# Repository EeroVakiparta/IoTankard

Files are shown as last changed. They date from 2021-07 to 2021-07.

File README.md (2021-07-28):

# IoTankard

Curious IoT test project.
Boardgames meet one handed beer drinking controller.

# Pin allocation

| Device | Pins | Notes |
| --- |:---: | ---:|
| MX Buttons | D4,D5,D6,D7 |  Add 10k resistors |
| HC-05 BT | D2,D3 | RX, TX |
| OLED I2D | A4,A5 | SCL, SDA |
| ADXL345 | D10,D11,D12,D13 | SPI |
| MotorDriver | D9 (PWM) | Only one needed |
| IF | A2 | |

3 free digital and 5 analog pins

# TODO

- Should the motor drive 2 directions
- Should I add capasitor for motor
- Come up with the connection to laptop
- Try accelerometer SPI communication with 3 wires instead of 4
- Fix double tap provoking a single tap after
- Measure batterylife for one 18650 cell.
- Better visuals for screen

# Buttons

MX cherry copies. The key caps are yet to be decided on.
Use normal keycaps for first version.

# Motor

6V basic motor was used. Went for low durability solution and soldered a big chunk at the tip of axis. With big motor it seems a bit challenging to do short fast wibrations.

# Infrared

Things learned
- The sensor stops working if the adjustment screw is over 80 or under 20% of its rotation. Maybe cheap part.

# Casing

The Ebin game remote which this was originally supposed to be went through few brainstorming phases and finally came to a handle design. The handle can be used for future projects. For example for a single hand MMO and beer drinking controller.

1. "The Wand"

2. "The Remote"

3. "The Tankard

Trying to see if everything fits inside | Modeled all parts | Closest to final product before first print
--- | --- | ---
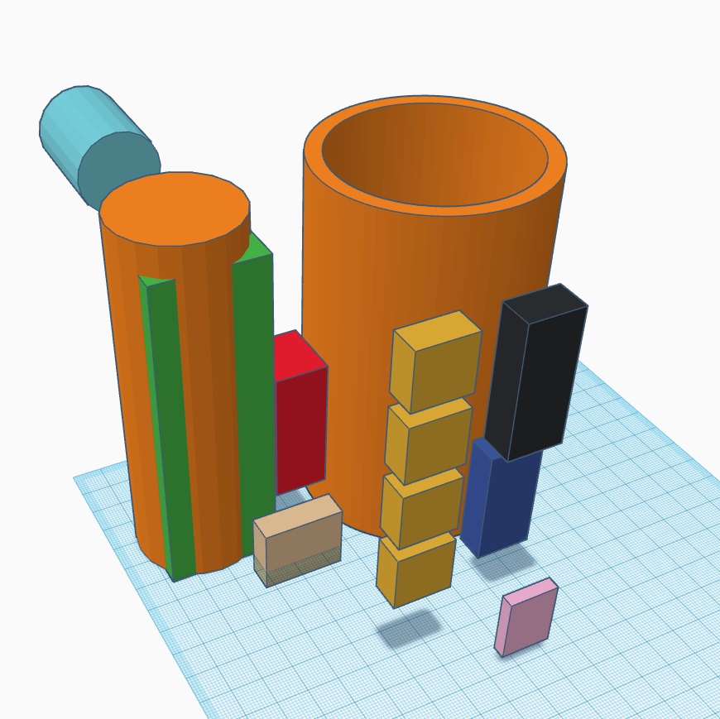
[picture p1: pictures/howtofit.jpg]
measuring how to fit everything
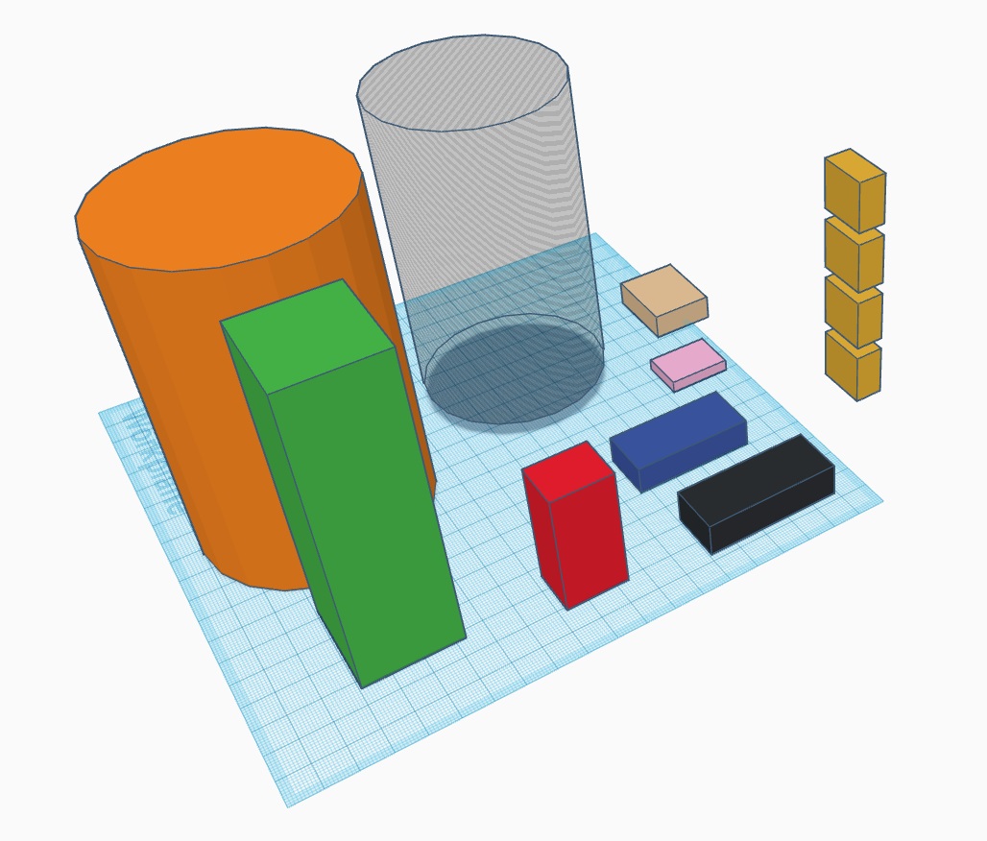
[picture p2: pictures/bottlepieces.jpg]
models of part needing to fit inside
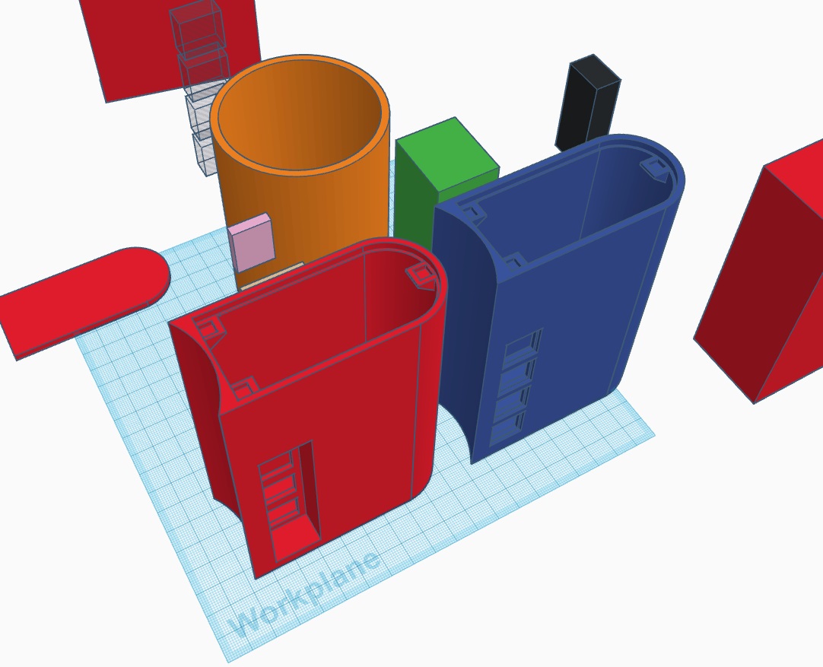
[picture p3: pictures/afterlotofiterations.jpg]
first good version
||

NOTE: next version will be done with fusion 360. At the moment of first desing I did not own any licenses to proper 3d design software.

# Bluetooth

Things learned
 - Do not spend hours of time debugging RX TX wires which are wrong way around.

The game engine this is made for can handle game controller inputs but for first version we went for bluetooth 
keyboard style and approach.

Converting the serial to key presses I used simple powershell script ( readCOM.ps1 )

```
    if ($port.IsOpen)
    {
        $data = $port.ReadLine()
        Add-Type -AssemblyName System.Windows.Forms
        [System.Windows.Forms.SendKeys]::SendWait($data);
```

| KEY | TRIGGER | NOTES | Ebin boardgame action | |
|-----|---|---|---|---|
| Q | Button | Index finger | Travel button | |
| W | Button | Middle finger | Dice | |
| E | Button | Ring finger | Group Dice | |
| R | Button | Pinkey finger | Biome Event | |
| ? | IR Sensor | Beer can removed | | |
| ? | IR Sensor | Beer can inserted | | |
| ? | Sensor | Swig taken (lenght adjustable) | | |
| ? | Sensor | Tankard falling from table | | |
| ? | Sensor | Tankard has not been in hand for 5 seconds (inactivity) | | |
| ? | Sensor | Tankard in hand | | |
| ? | Sensor | Tankard tapped on table | | |
| ? | Sensor | Tankard tapped to table twice | | |
| | Sensor | Beer can upside down (Bottoms up) | | |

Trying to explain what I'm doing to team | Some of the prototyping hardware
--- | --- 
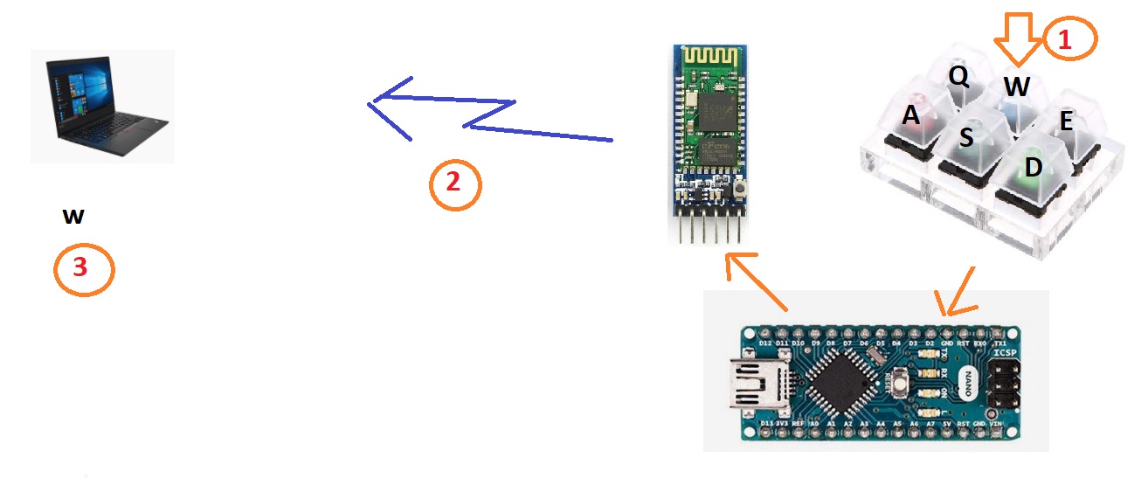
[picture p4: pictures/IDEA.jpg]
basic idea
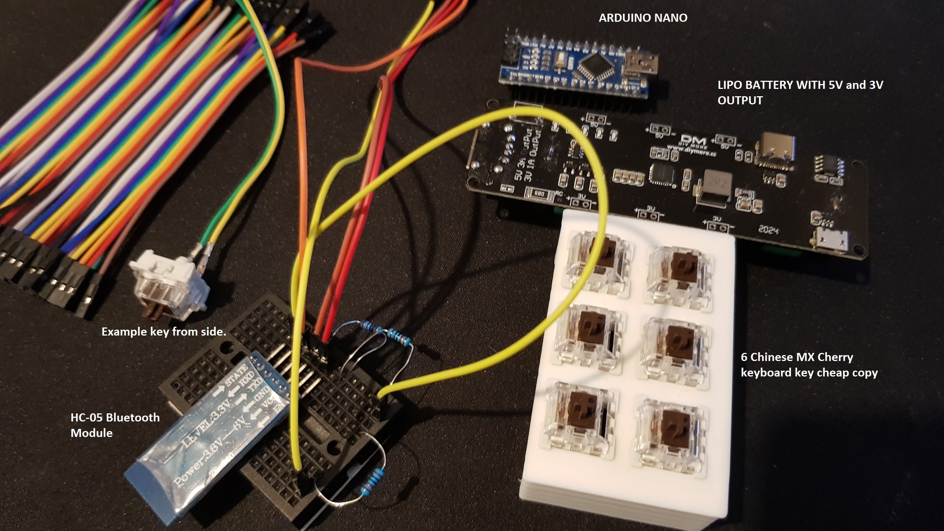
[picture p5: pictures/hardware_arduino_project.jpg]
 |

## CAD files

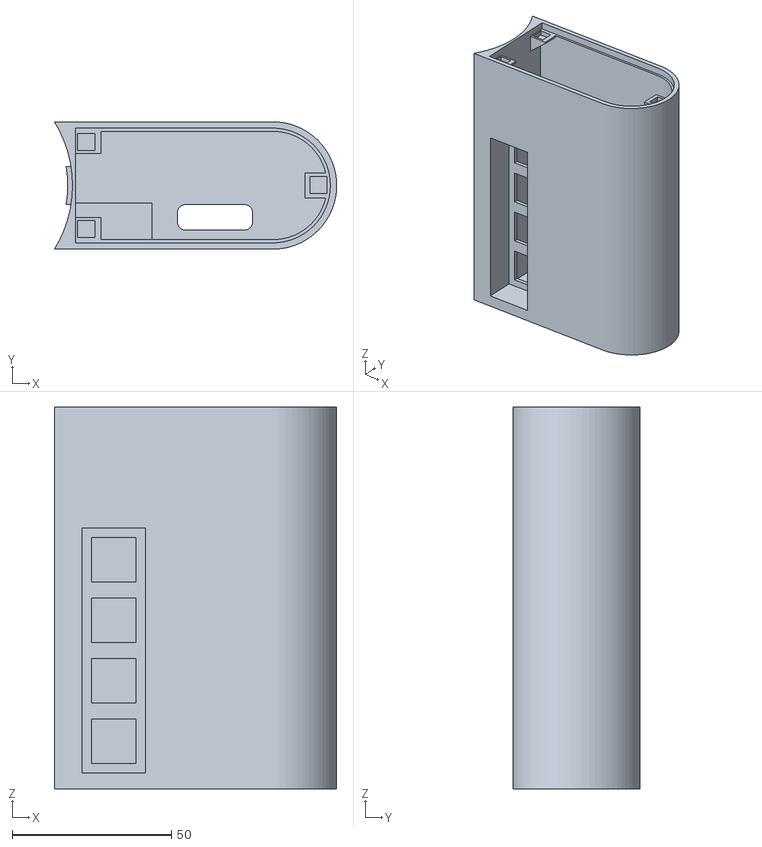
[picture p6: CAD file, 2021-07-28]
STL/handleversion_4.stl
88.7 x 40.0 x 120.0

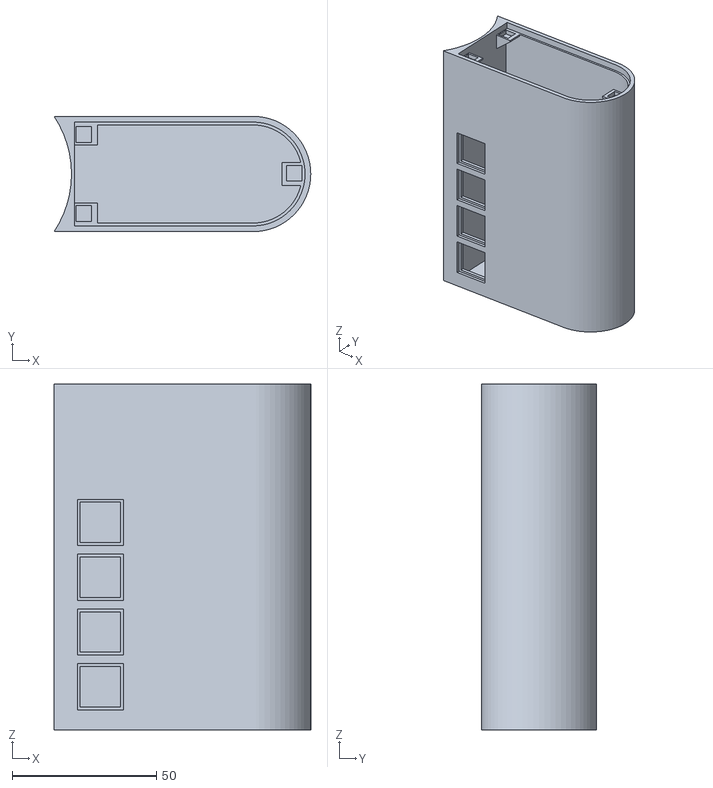
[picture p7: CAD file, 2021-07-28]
STL/handleversion_2.stl
89.0 x 40.0 x 120.0

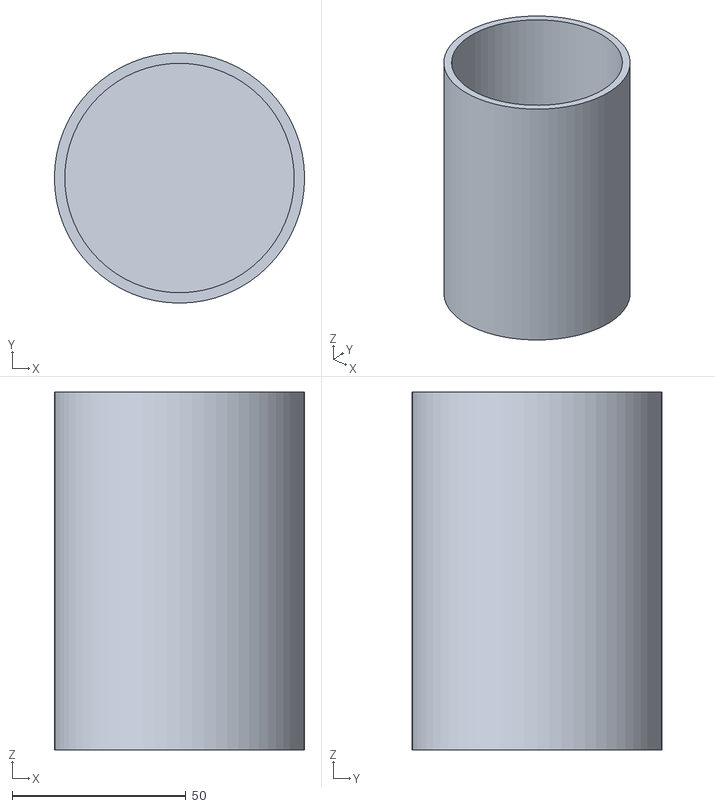
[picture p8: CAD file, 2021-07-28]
STL/canpart_1.stl
72.0 x 72.0 x 103.0

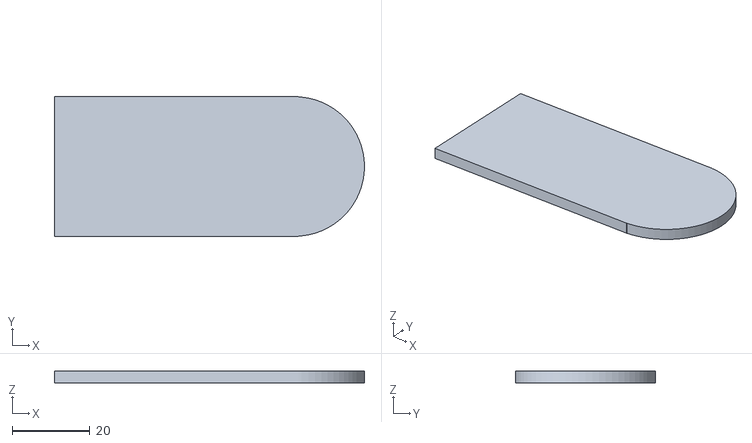
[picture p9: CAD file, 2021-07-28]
STL/lid.stl
80.0 x 36.0 x 3.00

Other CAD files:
STL/handleversion_1.stl
STL/handleversion_3.stl

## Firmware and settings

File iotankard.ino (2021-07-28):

#include <SparkFun_ADXL345.h> // accelerometer
#include <SoftwareSerial.h>  // Bluetooth

// Screen //
#include <SPI.h>
#include <Wire.h>
#include <Adafruit_GFX.h>
#include <Adafruit_SSD1306.h>

#define SCREEN_WIDTH 128 
#define SCREEN_HEIGHT 32 

#define OLED_RESET     -1 // Reset pin # (or -1 if sharing Arduino reset pin)
#define SCREEN_ADDRESS 0x3C ///< See datasheet for Address; 0x3D for 128x64, 0x3C for 128x32
Adafruit_SSD1306 display(SCREEN_WIDTH, SCREEN_HEIGHT, &Wire, OLED_RESET);

// Bluetooth //
SoftwareSerial bt(2,3); // RX/TS pins as parameters remember to cross wire these

// Accelerometer //
ADXL345 adxl = ADXL345(10);           // SPI com ADXL345(CS_PIN);

// Motor //
int IN1 = 9;
int motorSpeed = 10;
int maxVibrateSpeed = 255;
int minVibrateSpeed = 40;

// Buttons //
int buttonDelay = 100;
int buttonPressed = 0;

const int indexFinger_ButtonPin = 5;
const int middleFinger_ButtonPin = 6;
const int ringFinger_ButtonPin = 7;
const int pinkey_ButtonPin = 8;

int indexFinger_Btn;
int middleFinger_Btn;
int ringFinger_Btn;
int pinkey_Btn;

// IR sensor //
int IRsensor = A2;

// Status variables //
bool drinkLoaded = false;
bool sipTaken = false;
int sipcount = 0;

void setup() {
  Serial.begin(9600);
  bt.begin(9600);


  /* Screen */
  // SSD1306_SWITCHCAPVCC = generate display voltage from 3.3V internally
  if(!display.begin(SSD1306_SWITCHCAPVCC, SCREEN_ADDRESS)) {
    Serial.println(F("SSD1306 allocation failed"));
    for(;;); // Don't proceed, loop forever
  }

  // Clear the buffer
  display.clearDisplay();
  display.setCursor(0, 0);
  delay(200);
  
  
  adxl.powerOn();
  adxl.setRangeSetting(16);           // range in G (2,4,8,16) Drawback with higher Gs is lower sensitivity
  adxl.setSpiBit(0);                  // 0 = 4wire SPI , 1=3wire SPI

  adxl.setActivityXYZ(1, 0, 0);       // Which axis the activity feature uses
  adxl.setActivityThreshold(75);      // Adjust sensitivity of previous 62.5mg per increment (0-255)

  adxl.setInactivityXYZ(1, 0, 0);     // Which axis the inactivity feature uses
  adxl.setInactivityThreshold(75);    // 62.5mg per increment (0-255)
  adxl.setTimeInactivity(10);         // Sec to inactivity to activate

  adxl.setTapDetectionOnXYZ(0, 0, 1); // Selection of tap features axis

  adxl.setTapThreshold(50);           // 62.5 mg /step Tap strenght (0-255)
  adxl.setTapDuration(15);            // 625 μs /step
  adxl.setDoubleTapLatency(80);       // 1.25 ms /step Doubletap
  adxl.setDoubleTapWindow(200);       // 1.25 ms /step

  adxl.setFreeFallThreshold(7);       // Free fall (5 - 9) recommended - 62.5mg per increment (0-255)
  adxl.setFreeFallDuration(30);       // (20 - 70) recommended - 5ms per increment (0-255)

  adxl.ActivityINT(1); // Turn activity on
  adxl.InactivityINT(1); // Turn inactivity on
  adxl.singleTapINT(1); // Turn tap on
  adxl.doubleTapINT(1); // Turn double-tap on
  adxl.FreeFallINT(1); // Turn Free fall on

  /* Buttons */
  pinMode(indexFinger_ButtonPin, INPUT);
  pinMode(middleFinger_ButtonPin, INPUT);
  pinMode(ringFinger_ButtonPin, INPUT);
  pinMode(pinkey_ButtonPin, INPUT);

  /* Motor */
  pinMode(IN1, OUTPUT);
  pinMode(A1, OUTPUT);

  /* IR sensor */
  pinMode (IRsensor, INPUT);

  Serial.println("SETUP DONE");
  bt.println("BT SETUP DONE");
  drawtext("IoTankard");
  delay(10);
}

void loop() {
  
  if(digitalRead (IRsensor) == 0){
    //Serial.println("Beer loaded."); 
    drinkLoaded = true;
  }else{
    //Serial.println("Load beer now.");
    drinkLoaded = false;
  }
  
  buttonPressed = 0;
  
  // bt.println("BT ping"); // BT debugging
  
  // Accelerometer
  int x, y, z;
  adxl.readAccel(&x, &y, &z);
  Serial.print(x);
  Serial.print(", ");
  Serial.print(y);
  Serial.print(", ");
  Serial.println(z);
  delay(500);
  ADXL_ISR();

  if(sipTaken){
    if(x < 10 && y < 10 && x > -10 && y > -10){
      Serial.println("Reseting sip.");
      sipTaken = false;
    }
  }

  if(drinkLoaded && (x > 20 || y > 20 || x < -20 || y < -20) && !sipTaken){
    Serial.println("Sip taken ! ");
    sipcount++;
    Serial.print("Sips total: ");
    Serial.println(sipcount);
    sipTaken = true;
  }
 
  indexFinger_Btn = readButton(indexFinger_ButtonPin);
  middleFinger_Btn = readButton(middleFinger_ButtonPin);
  ringFinger_Btn = readButton(ringFinger_ButtonPin);
  pinkey_Btn = readButton(pinkey_ButtonPin);

  if (indexFinger_Btn == HIGH && buttonPressed == 0 ) {
    Serial.println("Q pressed ");
    bt.println("Q");
    buttonFeedback(1);
    delay(buttonDelay);
    buttonPressed = 1;
  } else if (middleFinger_Btn == HIGH && buttonPressed == 0) {
    Serial.println("W pressed ");
    bt.println("W");
    delay(buttonDelay);
    Pulse(10);
    buttonPressed = 1;
  } else if (ringFinger_Btn == HIGH && buttonPressed == 0) {
    Serial.println("E pressed ");
    bt.println("E");
    delay(buttonDelay);
    Climb(5);
    buttonPressed = 1;
  } else if (pinkey_Btn == HIGH && buttonPressed == 0) {
    Serial.println("R pressed ");
    bt.println("R");
    StopMotor();
    delay(buttonDelay);
    buttonPressed = 1;
  }
}

// --- Screen functions --- //
void drawtext(String texti) {
  display.clearDisplay();
  display.setTextSize(2); // Draw 2X-scale text
  display.setTextColor(SSD1306_WHITE);
  display.setCursor(10, 0);
  //display.println(F("test"));
  display.println(texti);
  display.display();      // Show initial text
  delay(100);
}

// --- Button functions --- //
int readButton(int pin) {
  pin = digitalRead(pin);
  if (pin == 1) {
    delay(50);
    pin = digitalRead(pin);
    if (pin == 0) {
      return HIGH;
    }
  }
}

// --- Motor functions --- //
void Pulse(int pulseCount) {
  for (int i = 0; i < pulseCount; i++ ) {
    analogWrite(IN1, maxVibrateSpeed);
    delay(100);
    analogWrite(IN1, 0);
    delay(100);
    Serial.println("Pulse");
  }
}

void Climb(int climbCount)
{
  for (int i = 0; i < climbCount; i++ ) {
    for (int i = minVibrateSpeed; i < maxVibrateSpeed; i = i + 5) {
      analogWrite(IN1, i);
      Serial.println(i);
      delay(20);
    }
    for (int i = maxVibrateSpeed; i > minVibrateSpeed; i = i - 5) {
      analogWrite(IN1, i);
      Serial.println(i);
      delay(20);
    }
    Serial.println("Climbed");
    Serial.println();
    analogWrite(IN1, 0);
  }
}

void StopMotor()
{
  digitalWrite(IN1, LOW);
  Serial.println("Stop Vibration");
}

void buttonFeedback(int pulseCount) {  
    analogWrite(IN1, maxVibrateSpeed);
    delay(15);
    analogWrite(IN1, 0);
    Serial.println("Button Feedback");
}

// --- Accelerometer functions --- //
void ADXL_ISR() {

  byte interrupts = adxl.getInterruptSource(); // clears all triggers

  if (adxl.triggered(interrupts, ADXL345_FREE_FALL)) {
    Serial.println("FREE FALL");
  }

  if (adxl.triggered(interrupts, ADXL345_INACTIVITY)) {
    Serial.println("INACTIVITY");
  }

  if (adxl.triggered(interrupts, ADXL345_ACTIVITY)) {
    Serial.println("ACTIVITY");
  }

  if (adxl.triggered(interrupts, ADXL345_DOUBLE_TAP)) {
    Serial.println("DOUBLE TAP");
  }

  if (adxl.triggered(interrupts, ADXL345_SINGLE_TAP)) {
    Serial.println("TAP");
  }
}

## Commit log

2021-07-20 Planned pins and did the finger buttons
2021-07-20 Added haptic feedback motor and 2 types of vibrations
    [iotankard.ino]
2021-07-21 Accelerometer added with extra features.
2021-07-28 Simple button feedback
2021-07-28 IR sensor and sip counter
2021-07-28 STL files and pictures
    [canpart_1.stl, handleversion_1.stl, handleversion_2.stl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]
